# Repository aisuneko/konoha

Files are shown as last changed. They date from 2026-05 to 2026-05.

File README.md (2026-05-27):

# Project "konoha"

4-port pure Type-C USB3.0 hub, based on WCH CH634X.

We have:
- All 4 ports in Type-C
- max. approx. USB3.2Gen1 transfer rate (~500MB/s); compatible with USB2.0
- Dedicated charging port
- Adequate ESD protection
- A symmetrical look
- One-sided components for ease of assembly

Name is inspired by Akisato Konoha from *16-bit Sensation*.

## Schematic

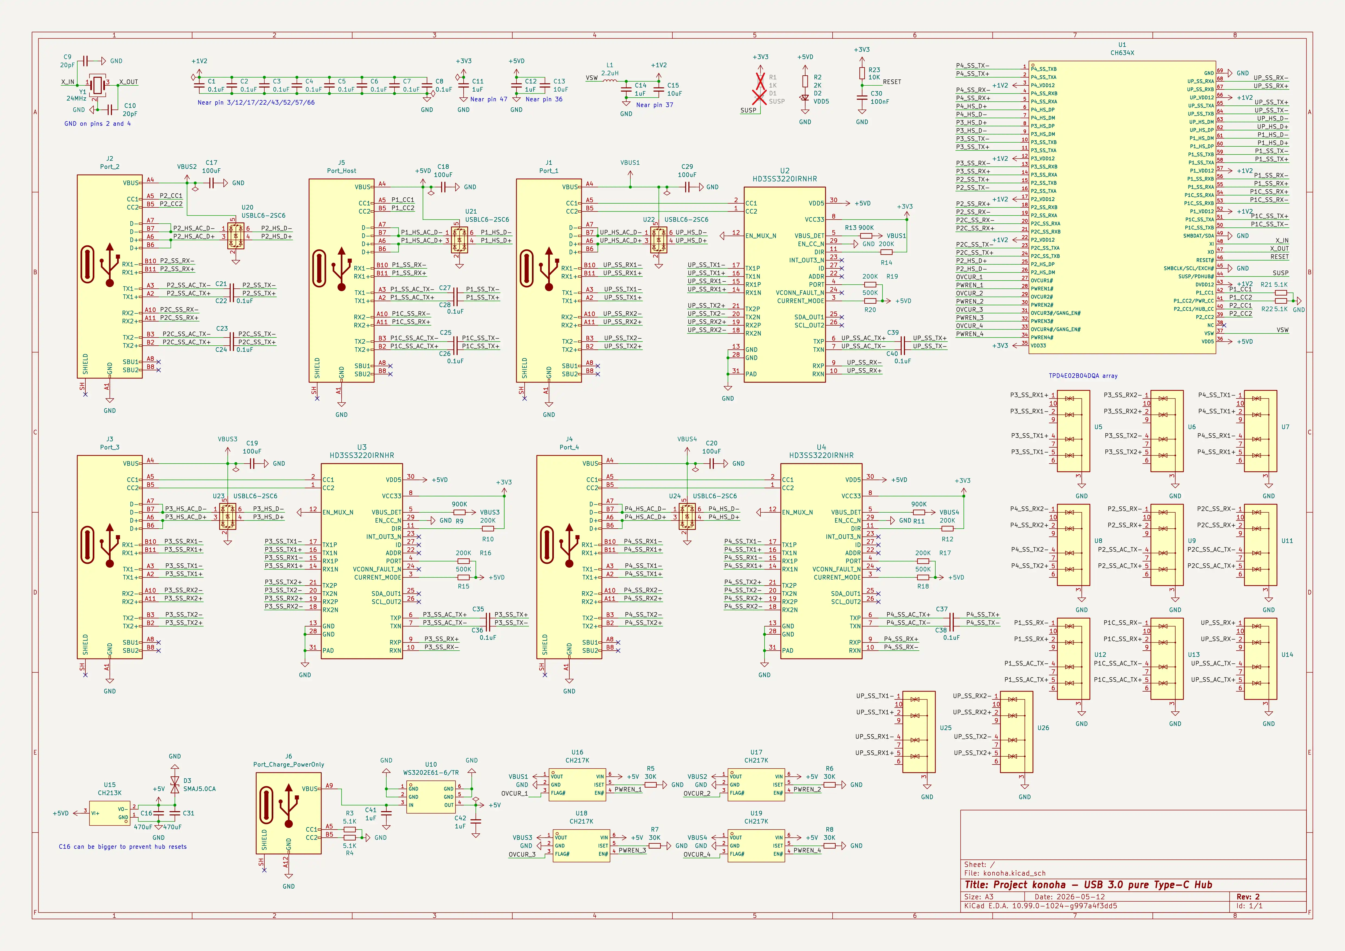
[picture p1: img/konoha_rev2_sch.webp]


Aside from my original idea of forcefully converting the three USB-A downstream ports provided by the CH634X to Type-C, it is largely based on CH634X's reference design with modifications.

Datasheets of the most important chips used in this design could be found under [docs](./docs/).

TL;DR: The USB-A to C conversion is done with TI's HD3SS3220 analog muxes (which appears to be as costly as the CH634X controller itself). CH217 is used for OVC protection while the CH213 diode realize the isolation between 5V and 5VD. ESD protection is realized by the TPD4E02B04 array (USBSS) and USBLC6-2SC6 (USBFS).

## Board

See the board in action:

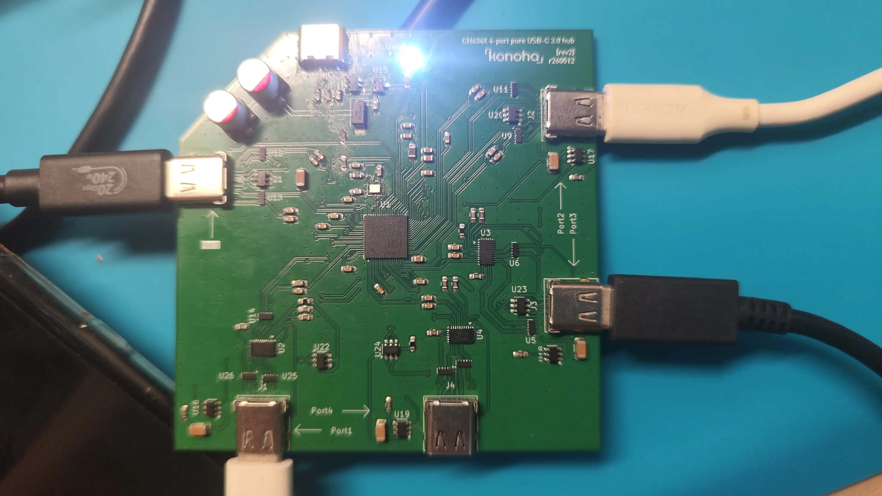
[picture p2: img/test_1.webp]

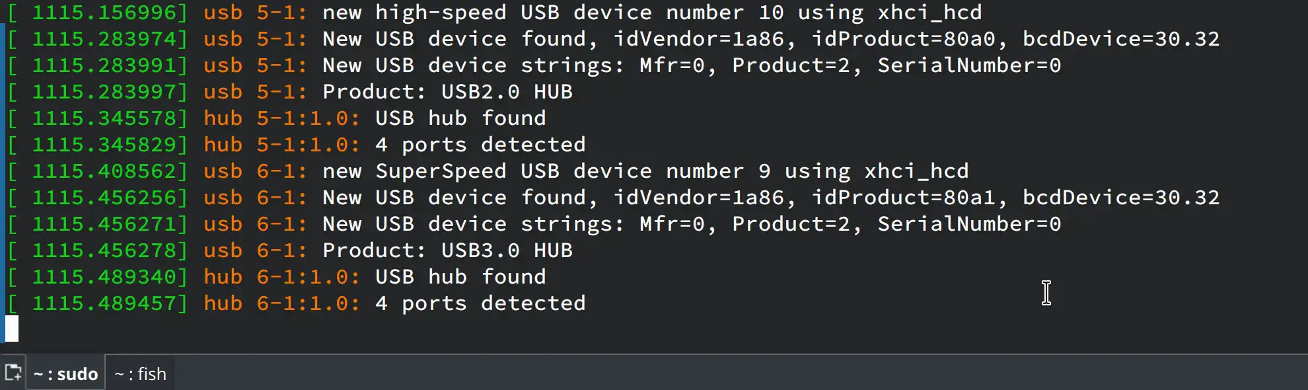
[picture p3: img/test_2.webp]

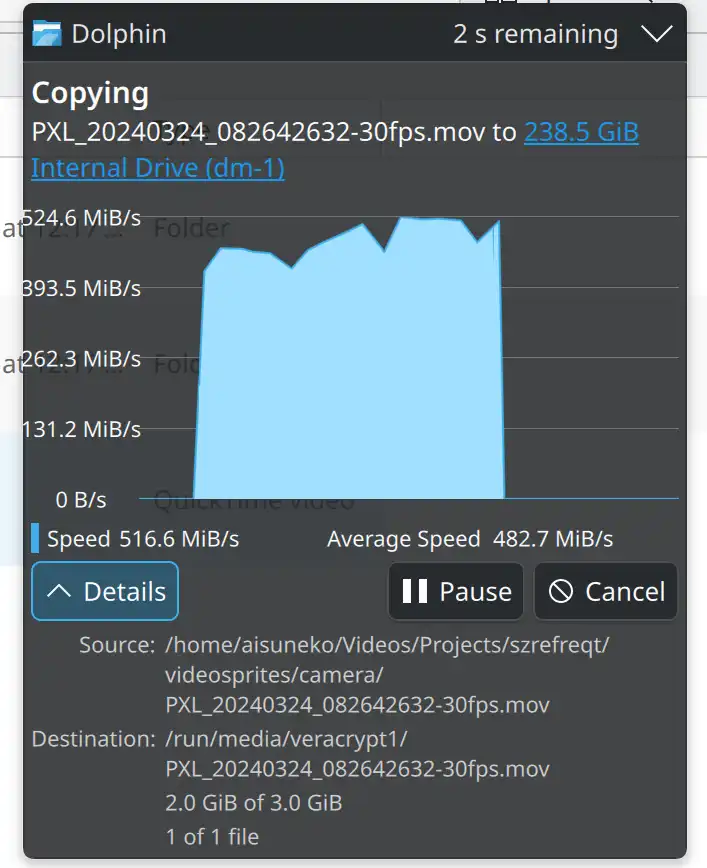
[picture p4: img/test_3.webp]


The board is fabricated using JLCPCB's default JLC04161H-3313 stackup so it should be fairly easy to order your own. Feel free to share any feedback and suggestions on the board design and component routing as I'm also new to high-speed PCB design.

## Caveats

- The board is rather unstable with multiple devices transferring data simultaneously. Certain ports might trigger an occassional hub reset with `disabled by hub (EMI?), re-enabling...` in dmesg.

  Will try to fix in the next revision by improving EMI at the shields of the Type-C connectors, as well as revising the power supply circuit to ensure it's sufficient.

- BOM costs are a bit high; I'll see if I can switch to a cheaper analog mux to reduce costs (and perhaps component count).

## Changelog

- rev1 (2025/11/28): first failed prototype. I can't get it soldered properly in the first place
- rev2 (2026/05/12): Initial working release

## License

As no firmware is involved in this project, it's under `CERN-OHL-S-2.0`.

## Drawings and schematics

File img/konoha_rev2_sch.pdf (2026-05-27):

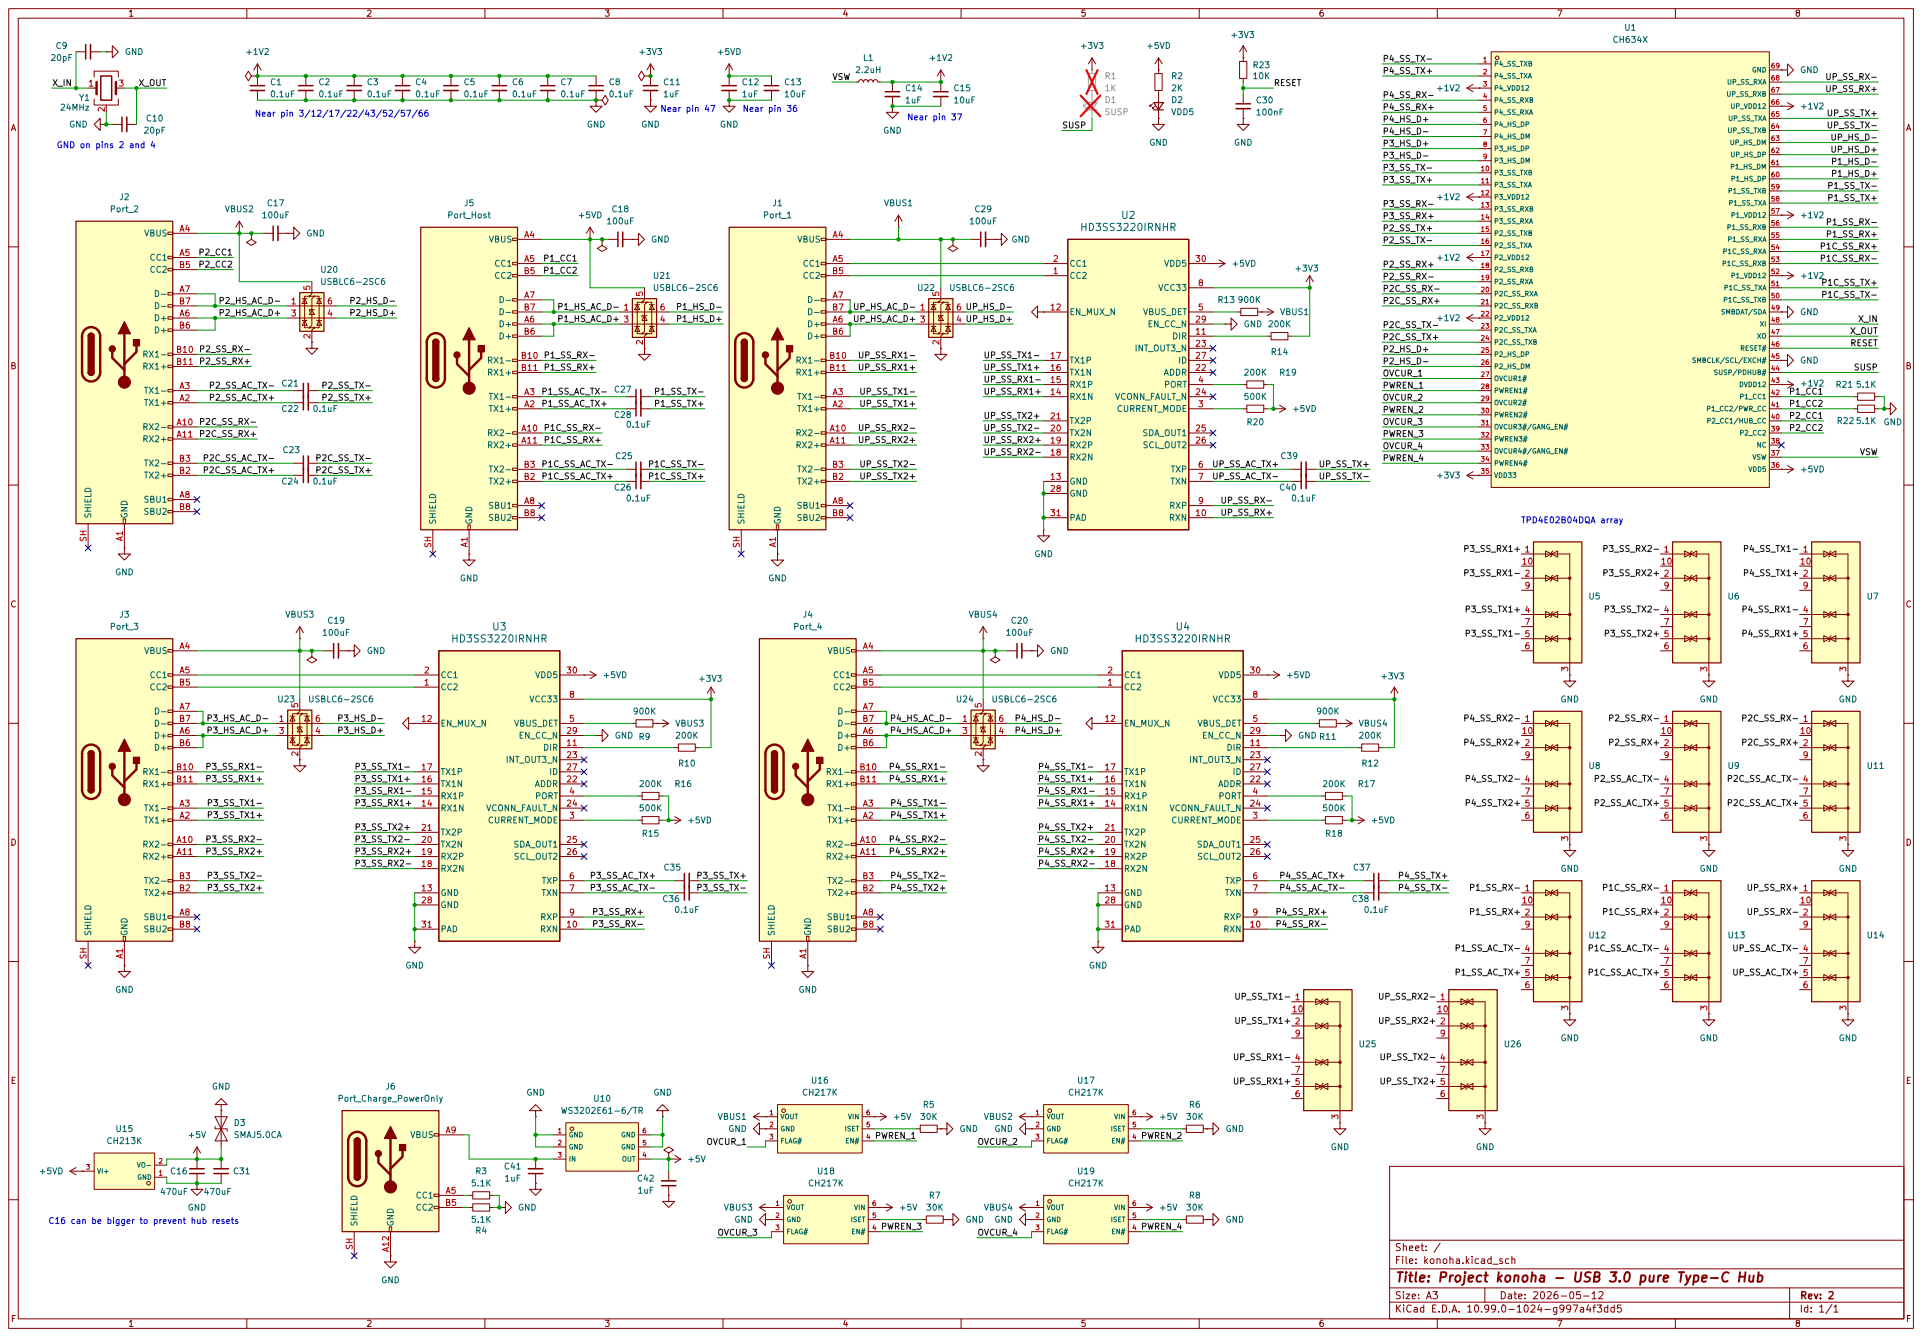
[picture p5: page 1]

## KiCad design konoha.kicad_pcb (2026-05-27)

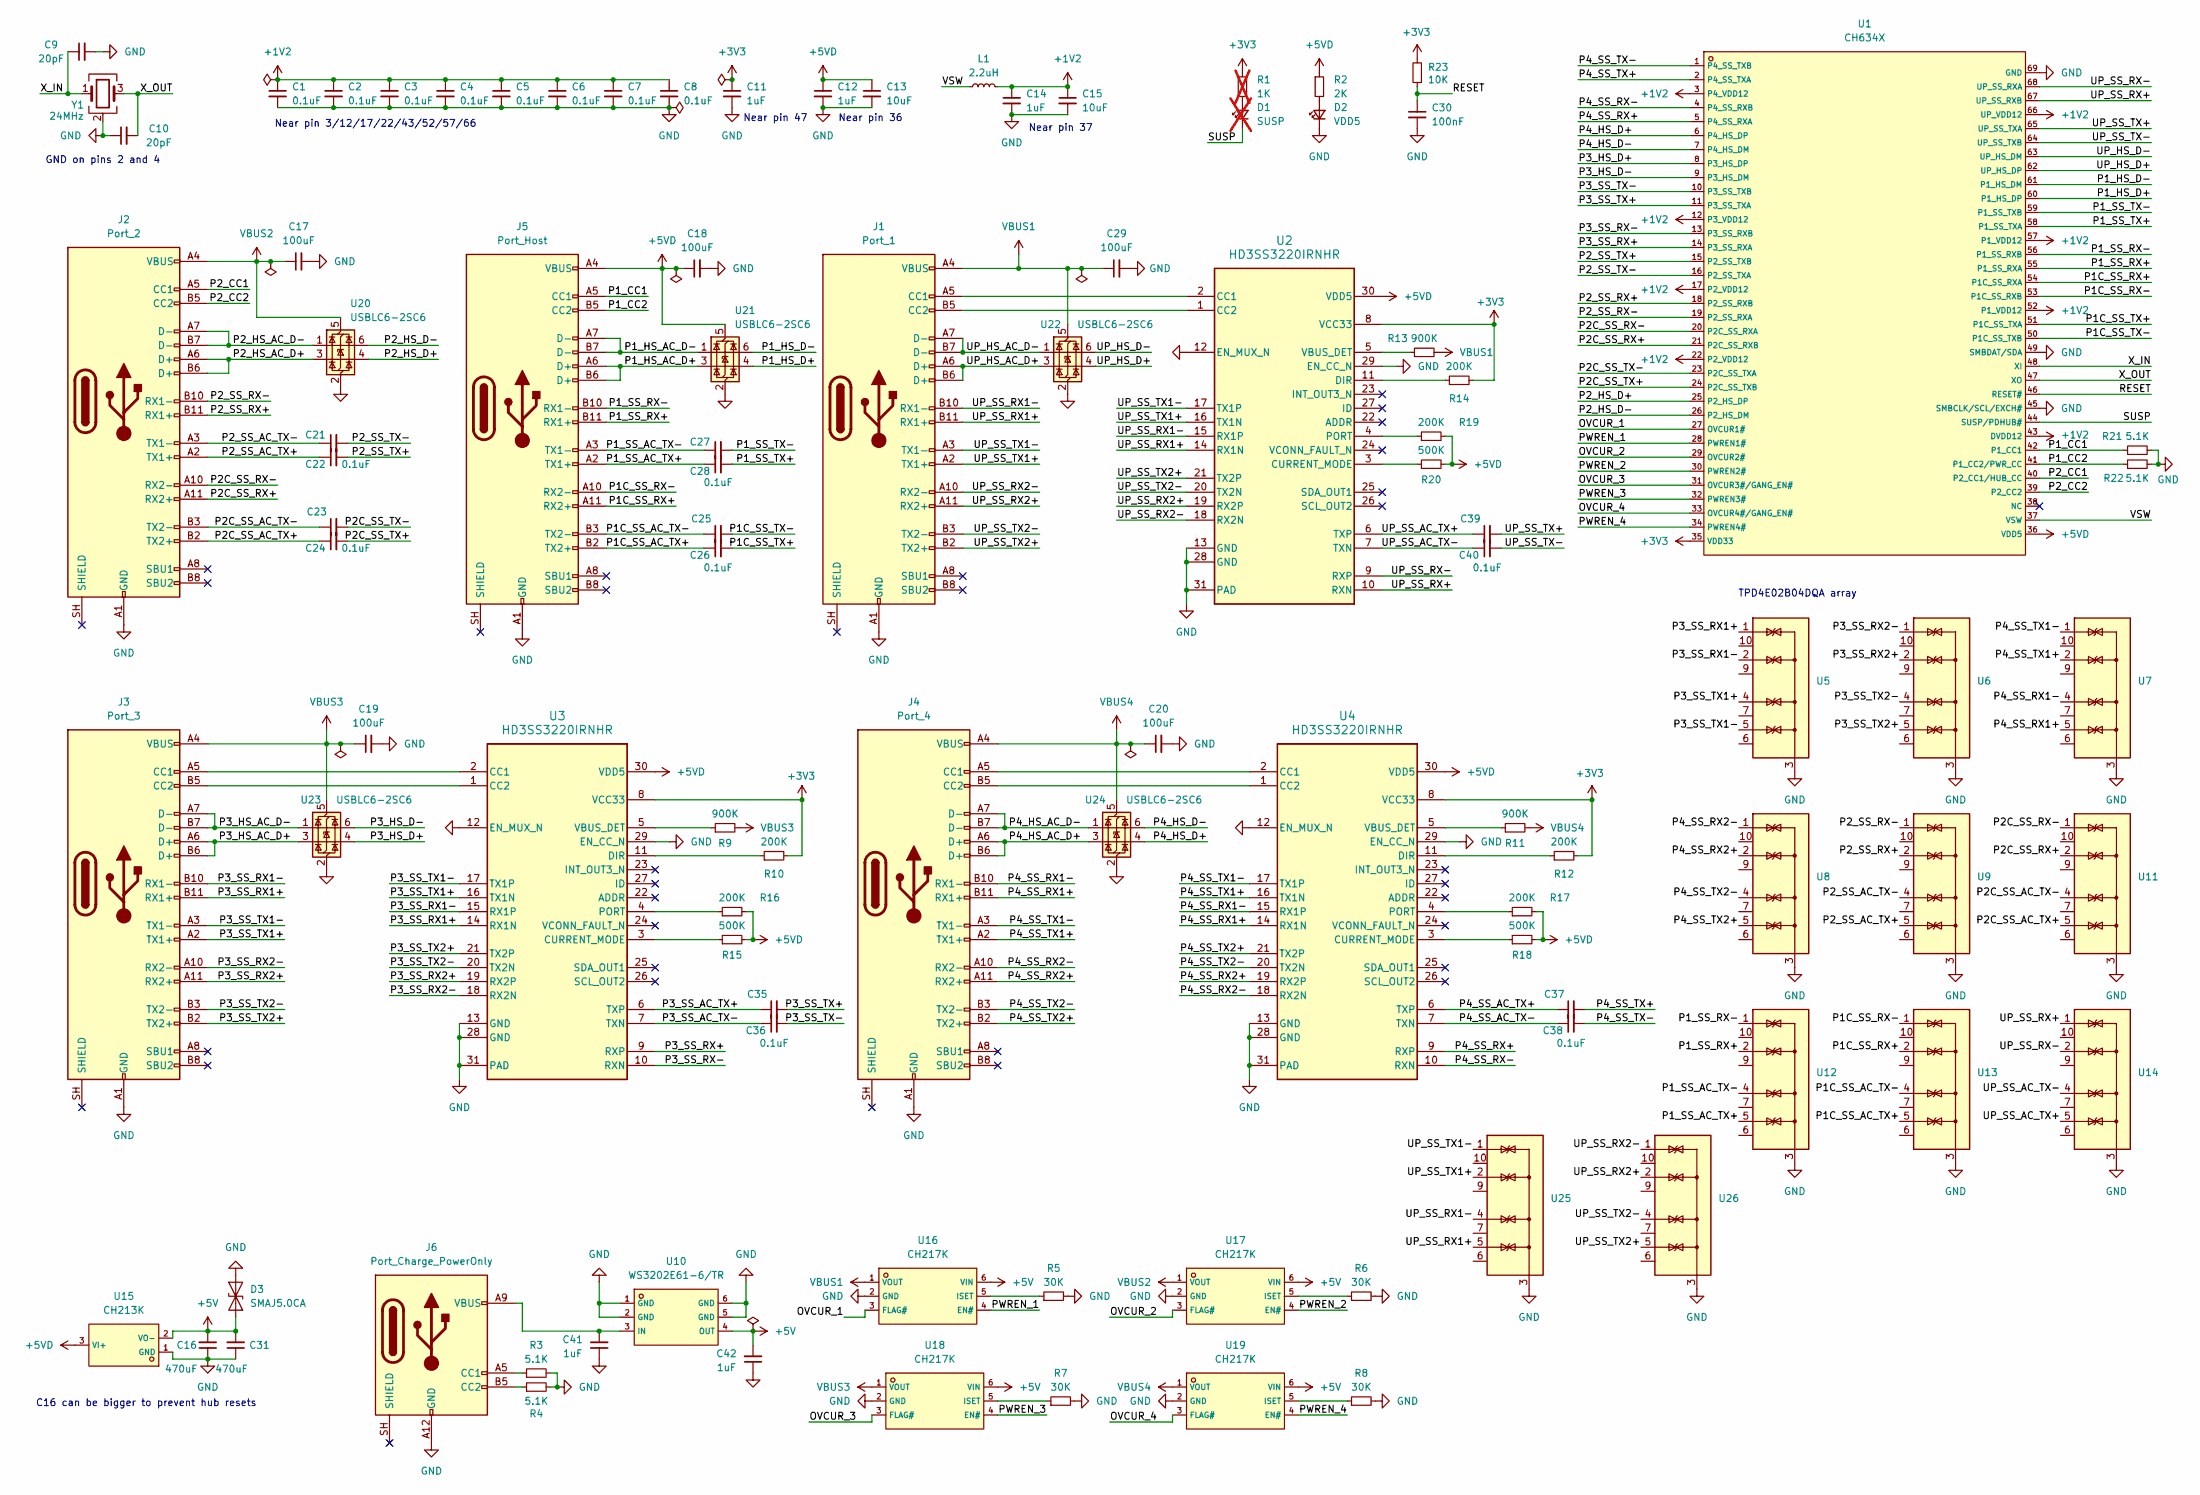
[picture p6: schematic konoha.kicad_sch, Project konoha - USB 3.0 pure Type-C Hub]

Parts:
C1, C2, C3, C4, C5, C6, C7, C8, C21, C22, C23, C24, C25, C26, C27, C28, C35, C36, C37, C38, C39, C40: 0.1uF; C_0603_1608Metric_Pad1.08x0.95mm_HandSolder
C9, C10: 20pF; C_0603_1608Metric_Pad1.08x0.95mm_HandSolder
C11, C12, C14, C41, C42: 1uF; C_0603_1608Metric_Pad1.08x0.95mm_HandSolder
C13, C15: 10uF; C_0603_1608Metric_Pad1.08x0.95mm_HandSolder
C16, C31: 470uF; CP_Elec_6.3x7.7
C17, C18, C19, C20, C29: 100uF; C_1206_3216Metric
C30: 100nF; C_0603_1608Metric_Pad1.08x0.95mm_HandSolder
D1: SUSP; LED_0805_2012Metric; not fitted
D2: VDD5; LED_0805_2012Metric
D3: SMAJ5.0CA; D_SMA
J1: Port_1; TYPE-C-USB-SMD_QCHT-143
J2: Port_2; TYPE-C-USB-SMD_QCHT-143
J3: Port_3; TYPE-C-USB-SMD_QCHT-143
J4: Port_4; TYPE-C-USB-SMD_QCHT-143
J5: Port_Host; TYPE-C-USB-SMD_QCHT-143
J6: Port_Charge_PowerOnly; USB_C_Receptacle_HRO_TYPE-C-31-M-17
L1: 2.2uH; L_0805_2012Metric_Pad1.05x1.20mm_HandSolder
R1: 1K; R_0603_1608Metric_Pad0.98x0.95mm_HandSolder; not fitted
R2: 2K; R_0603_1608Metric_Pad0.98x0.95mm_HandSolder
R3, R4, R21, R22: 5.1K; R_0603_1608Metric_Pad0.98x0.95mm_HandSolder
R5, R6, R7, R8: 30K; R_0603_1608Metric_Pad0.98x0.95mm_HandSolder
R9, R11, R13: 900K; R_0603_1608Metric_Pad0.98x0.95mm_HandSolder
R10, R12, R14, R16, R17, R19: 200K; R_0603_1608Metric_Pad0.98x0.95mm_HandSolder
R15, R18, R20: 500K; R_0603_1608Metric_Pad0.98x0.95mm_HandSolder
R23: 10K; R_0603_1608Metric_Pad0.98x0.95mm_HandSolder
U1: CH634X; QFN-68_L8.0-W8.0-P0.40-BL-EP6.2; LCSC C48985831
U2, U3, U4: HD3SS3220IRNHR; Texas_RNH0030A_WQFN-30-1EP_2.5x4.5mm_P0.4mm_EP1.2x3.2mm_The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
U5, U6, U7, U8, U9, U11, U12, U13, U14, U25, U26: TPD4E02B04DQA; USON-10_2.5x1.0mm_P0.5mm
U10: WS3202E61-6/TR; SOT-23-6_L2.9-W1.6-P0.95-LS2.8-BR; LCSC C191359
U15: CH213K; SOT-23-3_L2.9-W1.6-P1.90-LS2.8-BR; LCSC C5456874
U16, U17, U18, U19: CH217K; SOT-23-6_L2.9-W1.6-P0.95-LS2.8-BL; LCSC C7462749
U20, U21, U22, U23, U24: USBLC6-2SC6; SOT-23-6
Y1: 24MHz; Crystal_SMD_2016-4Pin_2.0x1.6mm

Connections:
+1V2: C1.1, C2.1, C3.1, C4.1, C5.1, C6.1, C7.1, C8.1, C14.1, C15.1, L1.2, U1.3 (P4_VDD12), U1.12 (P3_VDD12), U1.17 (P2_VDD12), U1.22 (P2_VDD12), U1.43 (DVDD12), U1.52 (P1_VDD12), U1.57 (P1_VDD12), U1.66 (UP_VDD12)
+3V3: C11.1, R1.1, R10.2, R12.2, R14.2, R23.2, U1.35 (VDD33), U2.8 (VCC33), U3.8 (VCC33), U4.8 (VCC33)
+5V: C16.2, C31.2, C42.2, D3.1 (A1), U10.4 (OUT), U15.2 (VO-), U16.6 (VIN), U17.6 (VIN), U18.6 (VIN), U19.6 (VIN)
+5VD: C12.1, C13.1, C18.1, J5.A4 (VBUS), J5.A9 (VBUS), J5.B4 (VBUS), J5.B9 (VBUS), R2.1, R15.2, R16.2, R17.2, R18.2, R19.2, R20.2, U1.36 (VDD5), U2.30 (VDD5), U3.30 (VDD5), U4.30 (VDD5), U15.3 (VI+), U21.5 (VBUS)
/OVCUR_1: U1.27 (OVCUR1#), U16.3 (FLAG#)
/OVCUR_2: U1.29 (OVCUR2#), U17.3 (FLAG#)
/OVCUR_3: U1.31 (OVCUR3#/GANG_EN#), U18.3 (FLAG#)
/OVCUR_4: U1.33 (OVCUR4#/GANG_EN#), U19.3 (FLAG#)
/P1C_SS_AC_TX+: C26.1, J5.B2 (TX2+), U13.5 (IO4)
/P1C_SS_AC_TX-: C25.1, J5.B3 (TX2-), U13.4 (IO3)
/P1C_SS_RX+: J5.A11 (RX2+), U1.54 (P1C_SS_RXA), U13.2 (IO2)
/P1C_SS_RX-: J5.A10 (RX2-), U1.53 (P1C_SS_RXB), U13.1 (IO1)
/P1C_SS_TX+: C26.2, U1.51 (P1C_SS_TXA)
/P1C_SS_TX-: C25.2, U1.50 (P1C_SS_TXB)
/P1_CC1: J5.A5 (CC1), R21.1, U1.42 (P1_CC1)
/P1_CC2: J5.B5 (CC2), R22.1, U1.41 (P1_CC2/PWR_CC)
/P1_HS_AC_D+: J5.A6 (D+), J5.B6 (D+), U21.3 (I/O2)
/P1_HS_AC_D-: J5.A7 (D-), J5.B7 (D-), U21.1 (I/O1)
/P1_HS_D+: U1.60 (P1_HS_DP), U21.4 (I/O2)
/P1_HS_D-: U1.61 (P1_HS_DM), U21.6 (I/O1)
/P1_SS_AC_TX+: C28.1, J5.A2 (TX1+), U12.5 (IO4)
/P1_SS_AC_TX-: C27.1, J5.A3 (TX1-), U12.4 (IO3)
/P1_SS_RX+: J5.B11 (RX1+), U1.55 (P1_SS_RXA), U12.2 (IO2)
/P1_SS_RX-: J5.B10 (RX1-), U1.56 (P1_SS_RXB), U12.1 (IO1)
/P1_SS_TX+: C28.2, U1.58 (P1_SS_TXA)
/P1_SS_TX-: C27.2, U1.59 (P1_SS_TXB)
/P2C_SS_AC_TX+: C24.1, J2.B2 (TX2+), U11.5 (IO4)
/P2C_SS_AC_TX-: C23.1, J2.B3 (TX2-), U11.4 (IO3)
/P2C_SS_RX+: J2.A11 (RX2+), U1.21 (P2C_SS_RXB), U11.2 (IO2)
/P2C_SS_RX-: J2.A10 (RX2-), U1.20 (P2C_SS_RXA), U11.1 (IO1)
/P2C_SS_TX+: C24.2, U1.24 (P2C_SS_TXB)
/P2C_SS_TX-: C23.2, U1.23 (P2C_SS_TXA)
/P2_CC1: J2.A5 (CC1), U1.40 (P2_CC1/HUB_CC)
/P2_CC2: J2.B5 (CC2), U1.39 (P2_CC2)
/P2_HS_AC_D+: J2.A6 (D+), J2.B6 (D+), U20.3 (I/O2)
/P2_HS_AC_D-: J2.A7 (D-), J2.B7 (D-), U20.1 (I/O1)
/P2_HS_D+: U1.25 (P2_HS_DP), U20.4 (I/O2)
/P2_HS_D-: U1.26 (P2_HS_DM), U20.6 (I/O1)
/P2_SS_AC_TX+: C22.1, J2.A2 (TX1+), U9.5 (IO4)
/P2_SS_AC_TX-: C21.1, J2.A3 (TX1-), U9.4 (IO3)
/P2_SS_RX+: J2.B11 (RX1+), U1.18 (P2_SS_RXB), U9.2 (IO2)
/P2_SS_RX-: J2.B10 (RX1-), U1.19 (P2_SS_RXA), U9.1 (IO1)
/P2_SS_TX+: C22.2, U1.15 (P2_SS_TXB)
/P2_SS_TX-: C21.2, U1.16 (P2_SS_TXA)
/P3_HS_AC_D+: J3.A6 (D+), J3.B6 (D+), U23.3 (I/O2)
/P3_HS_AC_D-: J3.A7 (D-), J3.B7 (D-), U23.1 (I/O1)
/P3_HS_D+: U1.8 (P3_HS_DP), U23.4 (I/O2)
/P3_HS_D-: U1.9 (P3_HS_DM), U23.6 (I/O1)
/P3_SS_AC_TX+: C35.1, U3.6 (TXP)
/P3_SS_AC_TX-: C36.1, U3.7 (TXN)
/P3_SS_RX1+: J3.B11 (RX1+), U3.14 (RX1N), U5.1 (IO1)
/P3_SS_RX1-: J3.B10 (RX1-), U3.15 (RX1P), U5.2 (IO2)
/P3_SS_RX2+: J3.A11 (RX2+), U3.19 (RX2P), U6.2 (IO2)
/P3_SS_RX2-: J3.A10 (RX2-), U3.18 (RX2N), U6.1 (IO1)
/P3_SS_RX+: U1.14 (P3_SS_RXA), U3.9 (RXP)
/P3_SS_RX-: U1.13 (P3_SS_RXB), U3.10 (RXN)
/P3_SS_TX1+: J3.A2 (TX1+), U3.16 (TX1N), U5.4 (IO3)
/P3_SS_TX1-: J3.A3 (TX1-), U3.17 (TX1P), U5.5 (IO4)
/P3_SS_TX2+: J3.B2 (TX2+), U3.21 (TX2P), U6.5 (IO4)
/P3_SS_TX2-: J3.B3 (TX2-), U3.20 (TX2N), U6.4 (IO3)
/P3_SS_TX+: C35.2, U1.11 (P3_SS_TXA)
/P3_SS_TX-: C36.2, U1.10 (P3_SS_TXB)
/P4_HS_AC_D+: J4.A6 (D+), J4.B6 (D+), U24.3 (I/O2)
/P4_HS_AC_D-: J4.A7 (D-), J4.B7 (D-), U24.1 (I/O1)
/P4_HS_D+: U1.6 (P4_HS_DP), U24.4 (I/O2)
/P4_HS_D-: U1.7 (P4_HS_DM), U24.6 (I/O1)
/P4_SS_AC_TX+: C37.1, U4.6 (TXP)
/P4_SS_AC_TX-: C38.1, U4.7 (TXN)
/P4_SS_RX1+: J4.B11 (RX1+), U4.14 (RX1N), U7.5 (IO4)
/P4_SS_RX1-: J4.B10 (RX1-), U4.15 (RX1P), U7.4 (IO3)
/P4_SS_RX2+: J4.A11 (RX2+), U4.19 (RX2P), U8.2 (IO2)
/P4_SS_RX2-: J4.A10 (RX2-), U4.18 (RX2N), U8.1 (IO1)
/P4_SS_RX+: U1.5 (P4_SS_RXA), U4.9 (RXP)
/P4_SS_RX-: U1.4 (P4_SS_RXB), U4.10 (RXN)
/P4_SS_TX1+: J4.A2 (TX1+), U4.16 (TX1N), U7.2 (IO2)
/P4_SS_TX1-: J4.A3 (TX1-), U4.17 (TX1P), U7.1 (IO1)
/P4_SS_TX2+: J4.B2 (TX2+), U4.21 (TX2P), U8.5 (IO4)
/P4_SS_TX2-: J4.B3 (TX2-), U4.20 (TX2N), U8.4 (IO3)
/P4_SS_TX+: C37.2, U1.2 (P4_SS_TXA)
/P4_SS_TX-: C38.2, U1.1 (P4_SS_TXB)
/PWREN_1: U1.28 (PWREN1#), U16.4 (EN#)
/PWREN_2: U1.30 (PWREN2#), U17.4 (EN#)
/PWREN_3: U1.32 (PWREN3#), U18.4 (EN#)
/PWREN_4: U1.34 (PWREN4#), U19.4 (EN#)
/RESET: C30.1, R23.1, U1.46 (RESET#)
/SUSP: D1.1 (K), U1.44 (SUSP/PDHUB#)
/UP_HS_AC_D+: J1.A6 (D+), J1.B6 (D+), U22.3 (I/O2)
/UP_HS_AC_D-: J1.A7 (D-), J1.B7 (D-), U22.1 (I/O1)
/UP_HS_D+: U1.62 (UP_HS_DP), U22.4 (I/O2)
/UP_HS_D-: U1.63 (UP_HS_DM), U22.6 (I/O1)
/UP_SS_AC_TX+: C39.1, U2.6 (TXP), U14.5 (IO4)
/UP_SS_AC_TX-: C40.1, U2.7 (TXN), U14.4 (IO3)
/UP_SS_RX1+: J1.B11 (RX1+), U2.14 (RX1N), U25.5 (IO4)
/UP_SS_RX1-: J1.B10 (RX1-), U2.15 (RX1P), U25.4 (IO3)
/UP_SS_RX2+: J1.A11 (RX2+), U2.19 (RX2P), U26.2 (IO2)
/UP_SS_RX2-: J1.A10 (RX2-), U2.18 (RX2N), U26.1 (IO1)
/UP_SS_RX+: U1.67 (UP_SS_RXB), U2.10 (RXN), U14.1 (IO1)
/UP_SS_RX-: U1.68 (UP_SS_RXA), U2.9 (RXP), U14.2 (IO2)
/UP_SS_TX1+: J1.A2 (TX1+), U2.16 (TX1N), U25.2 (IO2)
/UP_SS_TX1-: J1.A3 (TX1-), U2.17 (TX1P), U25.1 (IO1)
/UP_SS_TX2+: J1.B2 (TX2+), U2.21 (TX2P), U26.5 (IO4)
/UP_SS_TX2-: J1.B3 (TX2-), U2.20 (TX2N), U26.4 (IO3)
/UP_SS_TX+: C39.2, U1.65 (UP_SS_TXA)
/UP_SS_TX-: C40.2, U1.64 (UP_SS_TXB)
/VSW: L1.1, U1.37 (VSW)
/X_IN: C9.1, U1.48 (XI), Y1.1
/X_OUT: C10.2, U1.47 (XO), Y1.3
GND: C1.2, C2.2, C3.2, C4.2, C5.2, C6.2, C7.2, C8.2, C9.2, C10.1, C11.2, C12.2, C13.2, C14.2, C15.2, C16.1, C17.2, C18.2, C19.2, C20.2, C29.2, C30.2, C31.1, C41.1, C42.1, D2.1 (K), D3.2 (A2), J1.A1 (GND), J1.A12 (GND), J1.B1 (GND), J1.B12 (GND), J2.A1 (GND), J2.A12 (GND), J2.B1 (GND), J2.B12 (GND), J3.A1 (GND), J3.A12 (GND), J3.B1 (GND), J3.B12 (GND), J4.A1 (GND), J4.A12 (GND), J4.B1 (GND), J4.B12 (GND), J5.A1 (GND), J5.A12 (GND), J5.B1 (GND), J5.B12 (GND), J6.A12 (GND), J6.B12 (GND), R3.2, R4.2, R5.2, R6.2, R7.2, R8.2, R21.2, R22.2, U1.45 (SMBCLK/SCL/EXCH#), U1.49 (SMBDAT/SDA), U1.69 (GND), U2.12 (EN_MUX_N), U2.13 (GND), U2.28 (GND), U2.29 (EN_CC_N), U2.31 (PAD), U3.12 (EN_MUX_N), U3.13 (GND), U3.28 (GND), U3.29 (EN_CC_N), U3.31 (PAD), U4.12 (EN_MUX_N), U4.13 (GND), U4.28 (GND), U4.29 (EN_CC_N), U4.31 (PAD), U5.3 (G), U5.8 (G), U6.3 (G), U6.8 (G), U7.3 (G), U7.8 (G), U8.3 (G), U8.8 (G), U9.3 (G), U9.8 (G), U10.1 (GND), U10.2 (GND), U10.5 (GND), U10.6 (GND), U11.3 (G), U11.8 (G), U12.3 (G), U12.8 (G), U13.3 (G), U13.8 (G), U14.3 (G), U14.8 (G), U15.1 (GND), U16.2 (GND), U17.2 (GND), U18.2 (GND), U19.2 (GND), U20.2 (GND), U21.2 (GND), U22.2 (GND), U23.2 (GND), U24.2 (GND), U25.3 (G), U25.8 (G), U26.3 (G), U26.8 (G), Y1.2 (G), Y1.4 (G)
unnamed: D1.2 (A), R1.2
unnamed: D2.2 (A), R2.2
unnamed: J1.A5 (CC1), U2.2 (CC1)
unnamed: J1.B5 (CC2), U2.1 (CC2)
unnamed: J3.A5 (CC1), U3.2 (CC1)
unnamed: J3.B5 (CC2), U3.1 (CC2)
unnamed: J4.A5 (CC1), U4.2 (CC1)
unnamed: J4.B5 (CC2), U4.1 (CC2)
unnamed: J6.A5 (CC1), R3.1
unnamed: J6.B5 (CC2), R4.1
unnamed: R20.1, U2.3 (CURRENT_MODE)
unnamed: R14.1, U2.11 (DIR)
unnamed: R19.1, U2.4 (PORT)
unnamed: R13.1, U2.5 (VBUS_DET)
unnamed: R15.1, U3.3 (CURRENT_MODE)
unnamed: R10.1, U3.11 (DIR)
unnamed: R16.1, U3.4 (PORT)
unnamed: R9.1, U3.5 (VBUS_DET)
unnamed: R18.1, U4.3 (CURRENT_MODE)
unnamed: R12.1, U4.11 (DIR)
unnamed: R17.1, U4.4 (PORT)
unnamed: R11.1, U4.5 (VBUS_DET)
unnamed: C41.2, J6.A9 (VBUS), J6.B9 (VBUS), U10.3 (IN)
unnamed: R5.1, U16.5 (ISET)
unnamed: R6.1, U17.5 (ISET)
unnamed: R7.1, U18.5 (ISET)
unnamed: R8.1, U19.5 (ISET)
VBUS1: C29.1, J1.A4 (VBUS), J1.A9 (VBUS), J1.B4 (VBUS), J1.B9 (VBUS), R13.2, U16.1 (VOUT), U22.5 (VBUS)
VBUS2: C17.1, J2.A4 (VBUS), J2.A9 (VBUS), J2.B4 (VBUS), J2.B9 (VBUS), U17.1 (VOUT), U20.5 (VBUS)
VBUS3: C19.1, J3.A4 (VBUS), J3.A9 (VBUS), J3.B4 (VBUS), J3.B9 (VBUS), R9.2, U18.1 (VOUT), U23.5 (VBUS)
VBUS4: C20.1, J4.A4 (VBUS), J4.A9 (VBUS), J4.B4 (VBUS), J4.B9 (VBUS), R11.2, U19.1 (VOUT), U24.5 (VBUS)

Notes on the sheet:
Near pin 47
Near pin 36
Near pin 37
TPD4E02B04DQA array
Near pin 3/12/17/22/43/52/57/66
C16 can be bigger to prevent hub resets
GND on pins 2 and 4

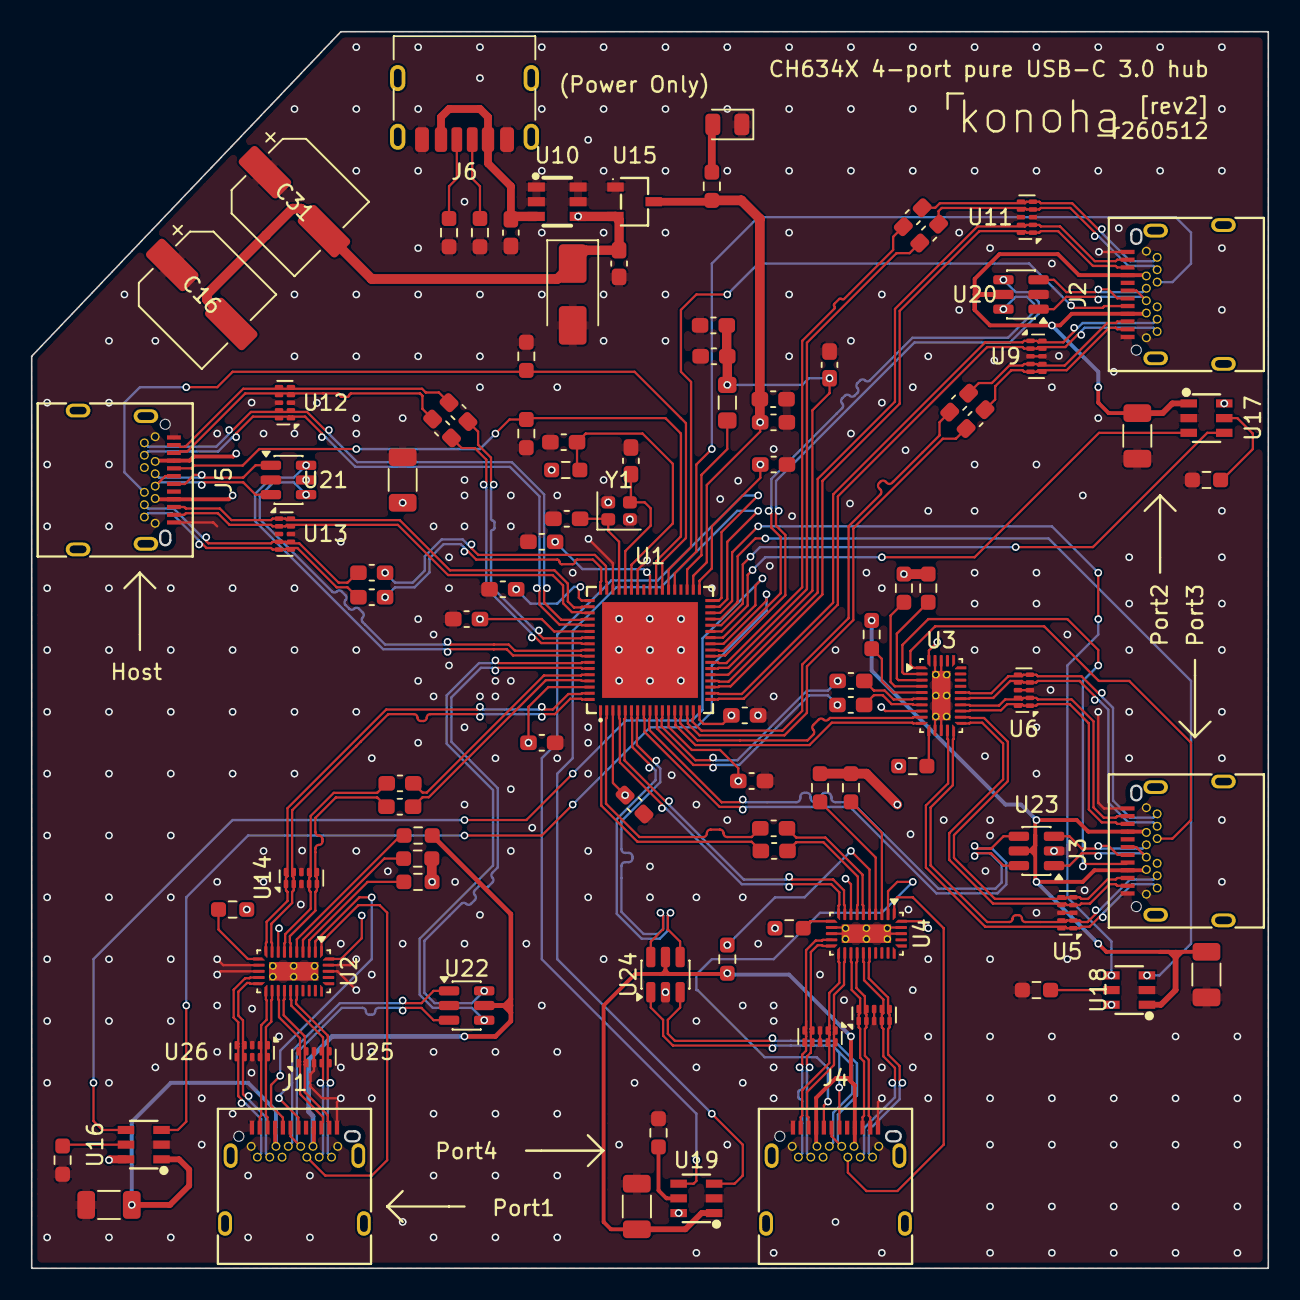
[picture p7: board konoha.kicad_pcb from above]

Board: 4 copper layers, 80.0 x 80.0 mm, 97 parts (0 on the bottom side), 137 nets.

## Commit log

2026-05-13 update symbols and footprints
2026-05-13 v2 schematic and board
    [konoha.kicad_pcb, konoha.kicad_sch]
2026-05-27 fix invalid rescue layer
    [konoha.kicad_pcb]
2026-05-27 update assets
    [konoha.kicad_pcb]
